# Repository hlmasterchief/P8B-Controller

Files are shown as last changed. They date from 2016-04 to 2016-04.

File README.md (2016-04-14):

# P8B-Controller
Repository for files for an open source gamepad using the Noridc NRF51822 microcontroller.

## Intro
This repository contains all files used to create a BLE gamepad using the Nordic NRF51822 microcontroller. I am using the MDBT40-P module that is approved by Nordic for this project instead of using the NRF51822 directly. 

## File Structure
The schematic and bill of materials can be found at the root layer and Gerber files for the layout can be found in the Gerber directory. The actual project files are found in the Controller directory and the project itself was created with a nightly build of [KiCad](http://kicad-pcb.org/). I used a nightly build because it addresses many issues I was having with the "stable" version of KiCad. For reference I am currently using revision 6687.

## License
This project is released under the Creative Commons Attribution and Share-alike license. The details can be found in LICENSE.txt but in summary, you can use the contents of this project however you want, including commercial use, if you:
1. Release your derivative projects/products with the same license as this one and
2. Attribute me in all derivative works.

###Author Info
[Nate Thompson](mailto:nate@prime8bit.com) <br/>
[http://prime8bit.com](http://prime8bit.com)

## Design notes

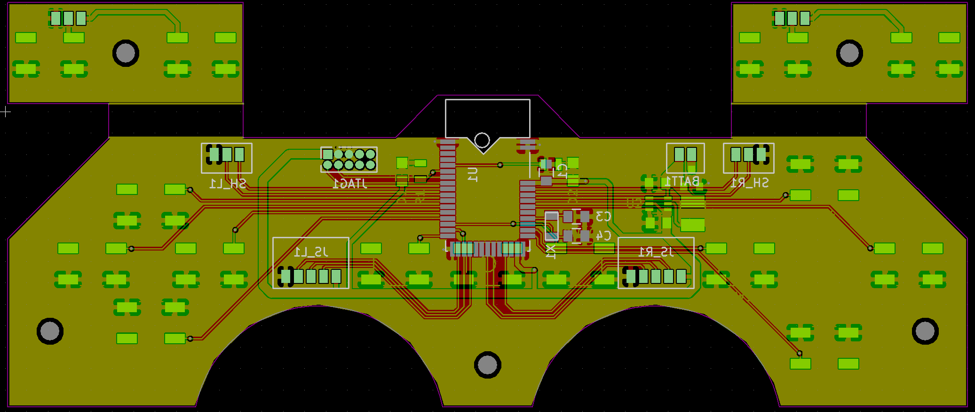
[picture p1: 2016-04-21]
Layout.PNG

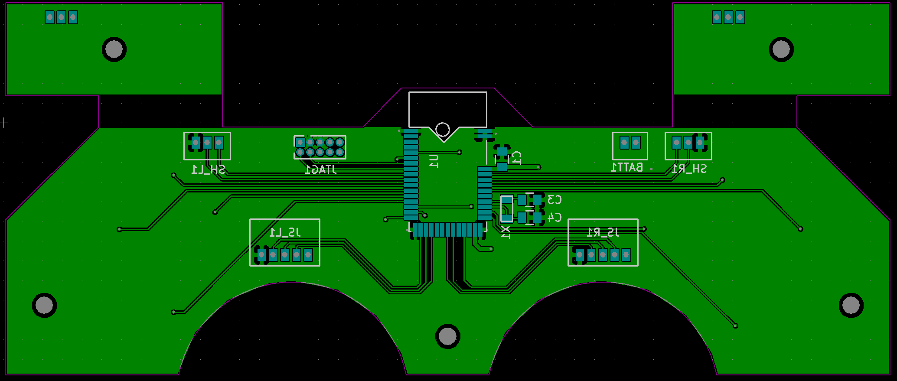
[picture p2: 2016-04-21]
Layout_Back.PNG

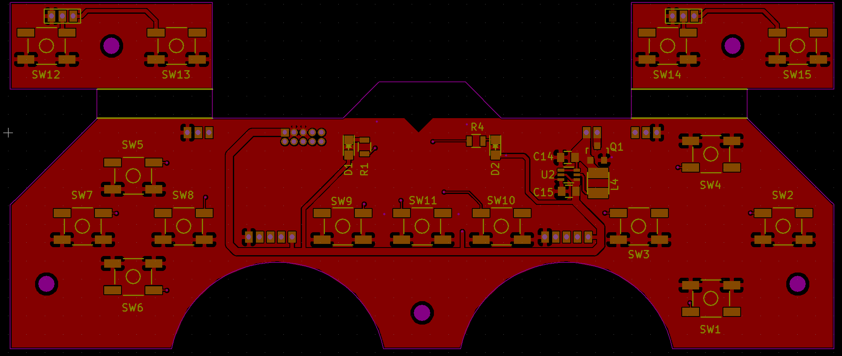
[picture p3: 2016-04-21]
Layout_Front.PNG

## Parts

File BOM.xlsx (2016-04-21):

Reference | Value | Quantity | Price | Price (1500) | Total per board | Total (1500) | Distributor Part Number | Manufacturer Part Number | Misc | Datasheet
R1, R4 | 68 | 2 | 0.1 | 0.00729 | 0.2 | 0.01458 | P68.0CCT-ND | ERJ-6ENF68R0V | RES SMD 68 OHM 1% 1/8W 0805 | http://www.digikey.com/product-detail/en/ERJ-6ENF68R0V/P68.0CCT-ND/1746895
C14, C15 | 10uF | 2 | 0.15 | 0.02888 | 0.3 | 0.05776 | 1276-1122-1-ND | CL21A106KQFNNNE | CAP CER 10UF 6.3V X5R 0805 | http://www.digikey.com/product-detail/en/CL21A106KQFNNNE/1276-1122-1-ND/3889208
C3, C4 | 12pF | 2 | 0.15 | 0.02833 | 0.3 | 0.05666 | 1276-2579-1-ND | CL21C120FBANNNC | Value | http://www.digikey.com/product-detail/en/CL21C120FBANNNC/1276-2579-1-ND/3890665
C1 | 1uF | 1 | 0.1 | 0.01077 | 0.1 | 0.01077 | 1276-1246-1-ND | CL21F105ZOCNNNC | CAP CER 1UF 16V Y5V 0805 | http://www.digikey.com/product-detail/en/CL21F105ZOCNNNC/1276-1246-1-ND/3889332
X1 | 32.768kHz | 1 | 0.76 | 0.4424 | 0.76 | 0.4424 | 1253-1335-1-ND | ST3215SB32768E0HPWBB | Crystal 32.7680kHz 20ppm 9pF 70 kOhm | http://www.digikey.com/product-detail/en/ST3215SB32768E0HPWBB/1253-1335-1-ND/4879221
L4 | 4.7uH | 1 | 0.34 | 0.1564 | 0.34 | 0.1564 | 587-1649-1-ND | NR3015T4R7M | FIXED IND 4.7UH 1.04A 144 MOHM | http://www.digikey.com/product-detail/en/NR3015T4R7M/587-1649-1-ND/1008264
SW1, SW2, SW3, SW4, SW5, SW6, SW7, SW8, SW9, SW10, SW11, SW12, SW13, SW14, SW15 | BUTTON | 15 | 0.65 | 0.3498 | 9.75 | 5.247 | CKN9104CT-ND | PTS525SM15SMTR2 LFS | SWITCH TACTILE SPST-NO 0.02A 15V | http://www.digikey.com/product-detail/en/PTS525SM15SMTR2%20LFS/CKN9104CT-ND/1146923
BATT1 | CONN_BATT | 1 | 0.17 | 0.07237 | 0.17 | 0.07237 | 455-1657-ND | S5B-ZR(LF)(SN) | CONN HEADER ZH TOP 2POS 1.5MM | http://www.digikey.com/product-detail/en/B2B-ZR(LF)(SN)/455-1657-ND/926564
JS_R1, JS_L1 | CONN_JOYSTICK_F | 2 | 0.29 | 0.13075 | 0.58 | 0.2615 | 455-1672-ND | S5B-ZR(LF)(SN) | CONN HEADER ZH SIDE 5POS 1.5MM | http://www.digikey.com/product-detail/en/S5B-ZR(LF)(SN)/455-1672-ND/926579
JTAG1 | CONN_JTAG | 1 | 0.64 | 0.33 | 0.64 | 0.33 | 609-3712-ND | 20021111-00010T4LF | JTAG | http://www.digikey.com/product-detail/en/20021111-00010T4LF/609-3712-ND/2209072
SH_L1, SH_R1 | CONN_SHOULDER | 2 | 0.18 | 0.08051 | 0.36 | 0.16102 | 455-1658-ND | B3B-ZR(LF)(SN) | CONN HEADER ZH TOP 3POS 1.5MM | http://www.digikey.com/product-search/en/connectors-interconnects/rectangular-connectors-headers-male-pins/1442547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
U1 | MDBT40-P | 1 | 7.5 | 5 | 7.5 | 5 | 317030026 | MDBT40P-P256V3 | Price(1500) is a guess | http://www.seeedstudio.com/depot/MDBT40P%C2%A0%C2%A0nRF51822%C2%A0based%C2%A0BLE%C2%A0module-p-2503.html
D1, D2 | ORANGE | 2 | 0.27 | 0.05031 | 0.54 | 0.10062 | 160-1413-1-ND | LTST-C170KFKT | LED ORANGE CLEAR 0805 SMD | http://www.digikey.com/product-detail/en/LTST-C170KFKT/160-1413-1-ND/386774
U2 | TPS61221 | 1 | 1.52 | 0.5575 | 1.52 | 0.5575 | 296-24171-2-ND | TPS61221DCKT | http://www.digikey.com/product-detail/en/TPS61221DCKT/296-24171-2-ND/2003233 | http://www.digikey.com/product-detail/en/TPS61221DCKT/296-24171-1-ND/2003239
Q1 | DMN2050L | 1 | 0.41 | 0.1575 | 0.41 | 0.1575 | DMN2050LDICT-ND | DMN2050L-7 | Alternate - SI2312 | http://www.digikey.com/product-detail/en/diodes-incorporated/DMN2050L-7/DMN2050LDICT-ND/1964751
Case | Case | 1 | 5 | 5 | 5 | 5
 |  |  |  | Total | 28.47 | 17.62608

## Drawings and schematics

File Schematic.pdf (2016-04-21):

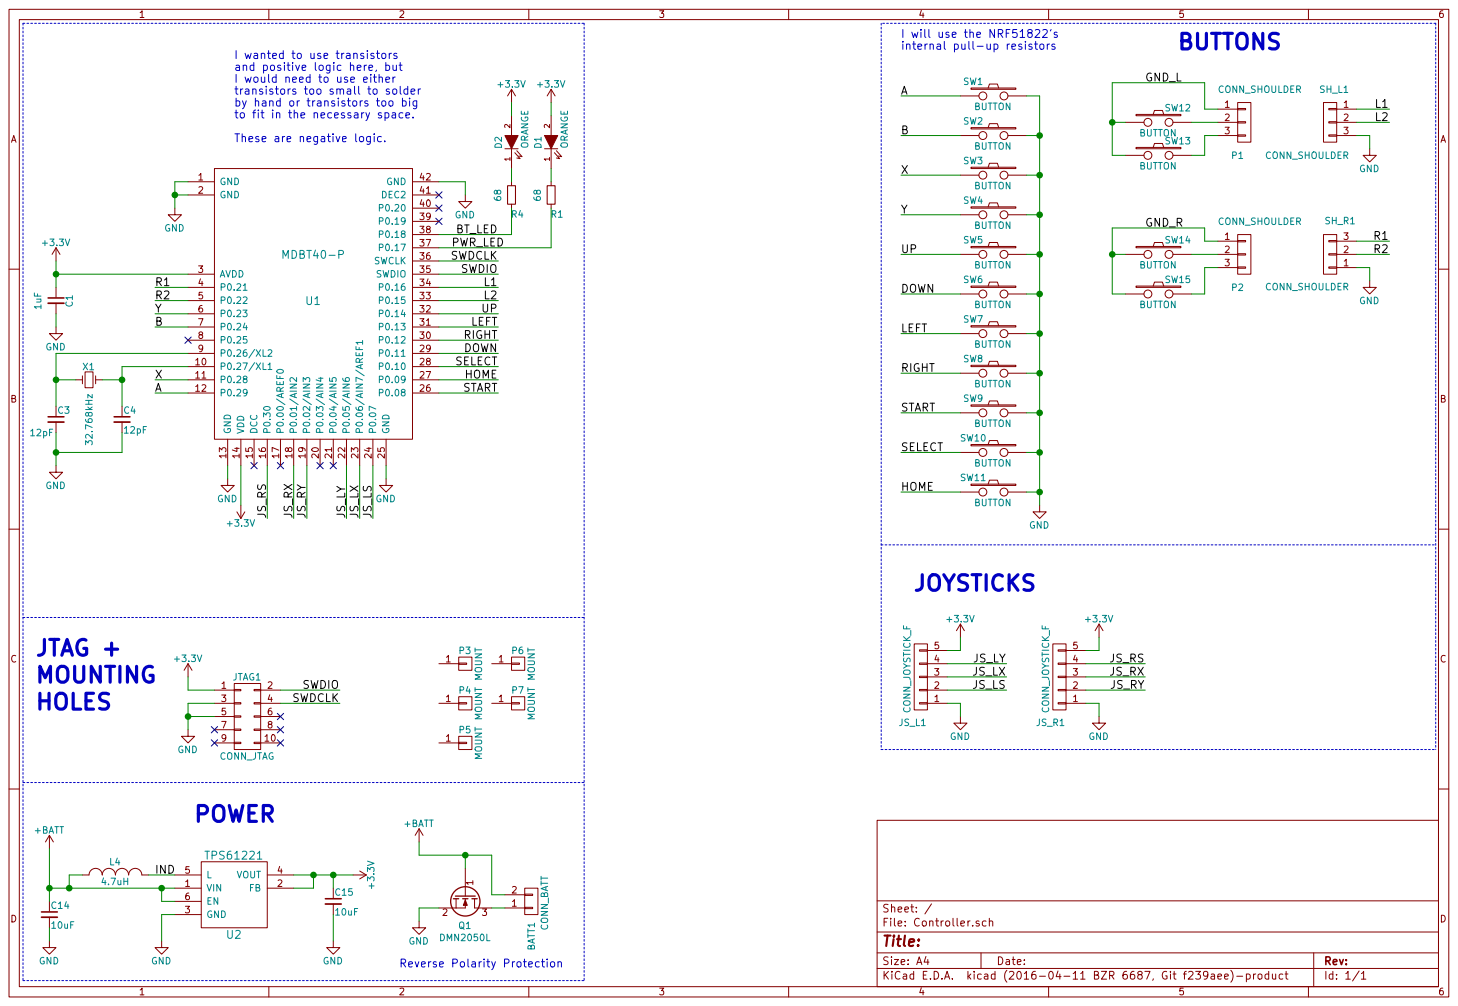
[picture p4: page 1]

I wanted to use transistors and positive logic here, but
I would need to use either
transistors too small to solder by hand or transistors too big
to fit in the necessary space.

Id: 1/1 Title: File: Controller.sch Sheet: /

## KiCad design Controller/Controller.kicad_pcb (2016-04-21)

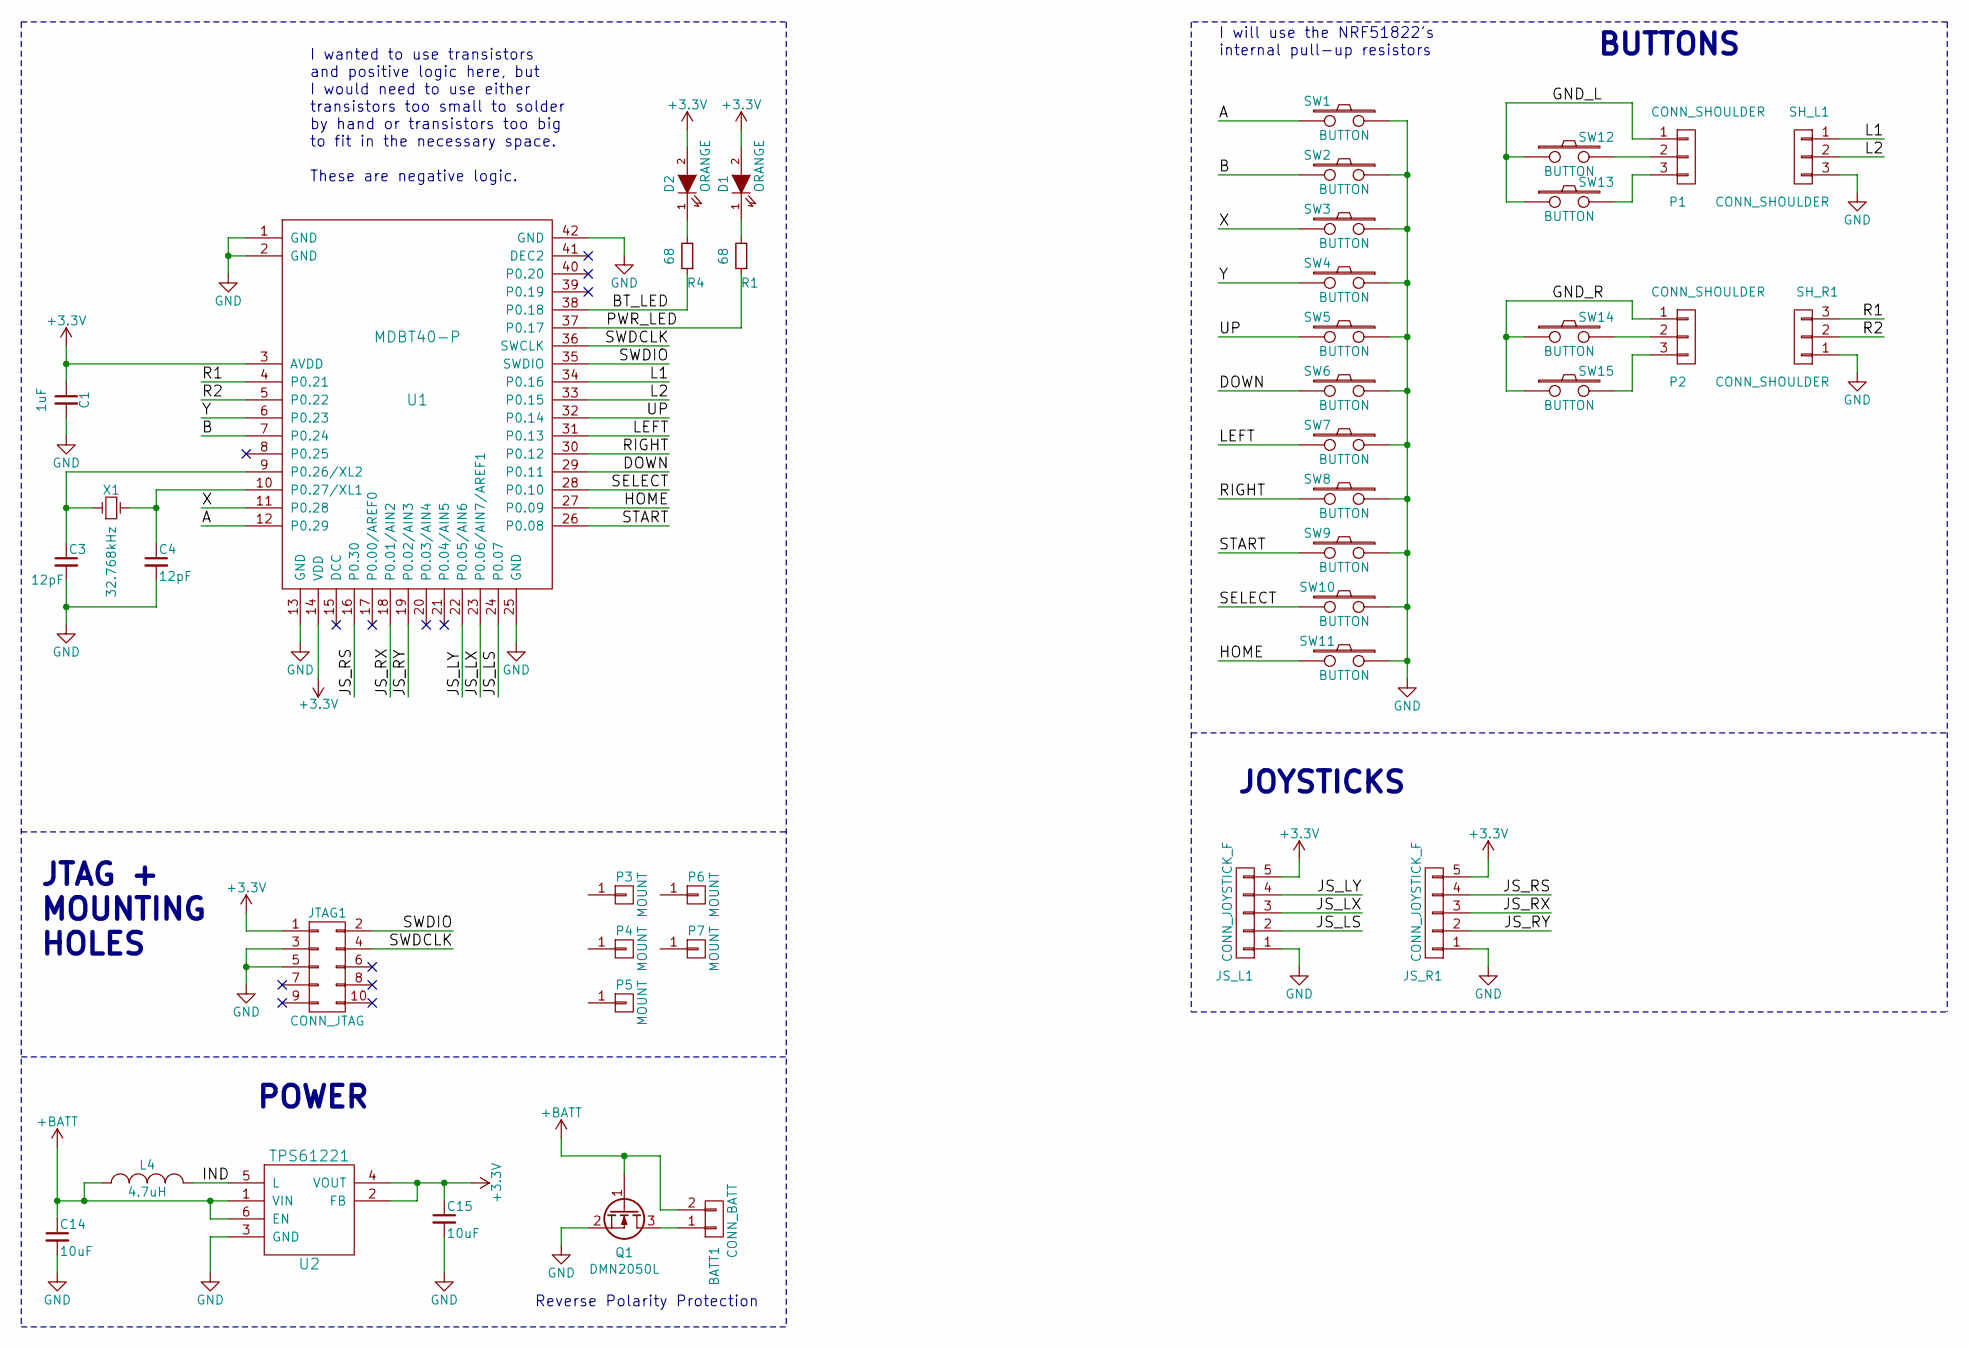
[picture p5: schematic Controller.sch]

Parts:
BATT1: CONN_BATT; Manufacturer Part Number S5B-ZR(LF)(SN)
C1: 1uF; C_0805; Manufacturer Part Number CL21F105ZOCNNNC
C3, C4: 12pF; C_0805; Manufacturer Part Number CL21C120FBANNNC
C14, C15: 10uF; C_0805; Manufacturer Part Number CL21A106KQFNNNE
D1, D2: ORANGE; LED_0805; Manufacturer Part Number LTST-C170KFKT
JS_L1: CONN_JOYSTICK_F; CONN_JOYSTICK; Manufacturer Part Number S5B-ZR(LF)(SN)
JS_R1: CONN_JOYSTICK_F; CONN_JOYSTICK; Manufacturer Part Number S5B-ZR(LF)(SN)
JTAG1: CONN_JTAG; Pin_Header_Straight_2x05_Pitch1.27mm; Manufacturer Part Number 20021111-00010T4LF
L4: 4.7uH; NR3015T4R7M; Manufacturer Part Number NR3015T4R7M
P1, P2: CONN_SHOULDER; CONN_SHOULDER_M; Manufacturer Part Number B3B-ZR(LF)(SN)
P3, P4, P5, P6, P7: MOUNT; Mounting_#2
Q1: DMN2050L; SOT-23-3; Manufacturer Part Number DMN2050L-7
R1, R4: 68; R_0805; Manufacturer Part Number ERJ-6ENF68R0V
SH_L1: CONN_SHOULDER; CONN_SHOULDER_F; Manufacturer Part Number B3B-ZR(LF)(SN)
SH_R1: CONN_SHOULDER; CONN_SHOULDER_F; Manufacturer Part Number B3B-ZR(LF)(SN)
SW1, SW2, SW3, SW4, SW5, SW6, SW7, SW8, SW9, SW10, SW11, SW12, SW13, SW14, SW15: BUTTON; SW_BUTTON; Manufacturer Part Number PTS525SM15SMTR2 LFS
U1: MDBT40-P; Manufacturer Part Number MDBT40P-P256V3
U2: TPS61221; Manufacturer Part Number TPS61221DCKT
X1: 32.768kHz; Manufacturer Part Number ST3215SB32768E0HPWBB

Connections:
+3V3: C1.1, C15.1, D1.2 (A), D2.2 (A), JS_L1.5, JS_R1.5, JTAG1.1, U1.3 (AVDD), U1.14 (VDD), U2.2 (FB), U2.4 (VOUT)
+BATT: BATT1.2, C14.1, L4.1, Q1.1 (G), U2.1 (VIN), U2.6 (EN)
/A: SW1.2, U1.12 (P0.29)
/B: SW2.2, U1.7 (P0.24)
/BT_LED: R4.1, U1.38 (P0.18)
/DOWN: SW6.2, U1.29 (P0.11)
/GND_L: P1.1, SW12.1, SW13.1
/GND_R: P2.1, SW14.1, SW15.1
/HOME: SW11.2, U1.27 (P0.09)
/IND: L4.2, U2.5 (L)
/JS_LS: JS_L1.2, U1.24 (P0.07)
/JS_LX: JS_L1.3, U1.23 (P0.06/AIN7/AREF1)
/JS_LY: JS_L1.4, U1.22 (P0.05/AIN6)
/JS_RS: JS_R1.4, U1.16 (P0.30)
/JS_RX: JS_R1.3, U1.18 (P0.01/AIN2)
/JS_RY: JS_R1.2, U1.19 (P0.02/AIN3)
/L1: SH_L1.1, U1.34 (P0.16)
/L2: SH_L1.2, U1.33 (P0.15)
/LEFT: SW7.2, U1.31 (P0.13)
/PWR_LED: R1.1, U1.37 (P0.17)
/R1: SH_R1.3, U1.4 (P0.21)
/R2: SH_R1.2, U1.5 (P0.22)
/RIGHT: SW8.2, U1.30 (P0.12)
/SELECT: SW10.2, U1.28 (P0.10)
/START: SW9.2, U1.26 (P0.08)
/SWDCLK: JTAG1.4, U1.36 (SWCLK)
/SWDIO: JTAG1.2, U1.35 (SWDIO)
/UP: SW5.2, U1.32 (P0.14)
/X: SW3.2, U1.11 (P0.28)
/Y: SW4.2, U1.6 (P0.23)
GND: C1.2, C3.2, C4.2, C14.2, C15.2, JS_L1.1, JS_R1.1, JTAG1.3, JTAG1.5, Q1.2 (S), SH_L1.3, SH_R1.1, SW1.1, SW2.1, SW3.1, SW4.1, SW5.1, SW6.1, SW7.1, SW8.1, SW9.1, SW10.1, SW11.1, U1.1 (GND), U1.2 (GND), U1.13 (GND), U1.25 (GND), U1.42 (GND), U2.3 (GND)
unnamed: BATT1.1, Q1.3 (D)
unnamed: C3.1, U1.9 (P0.26/XL2), X1.1
unnamed: C4.1, U1.10 (P0.27/XL1), X1.2
unnamed: D1.1 (K), R1.2
unnamed: D2.1 (K), R4.2
unnamed: P1.2, SW12.2
unnamed: P1.3, SW13.2
unnamed: P2.2, SW14.2
unnamed: P2.3, SW15.2

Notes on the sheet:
POWER
JTAG + MOUNTING HOLES
I wanted to use transistors and positive logic here, but I would need to use either transistors too small to solder by hand or transistors too big to fit in the necessary space. These are negative logic.
Reverse Polarity Protection
I will use the NRF51822's internal pull-up resistors
BUTTONS
JOYSTICKS

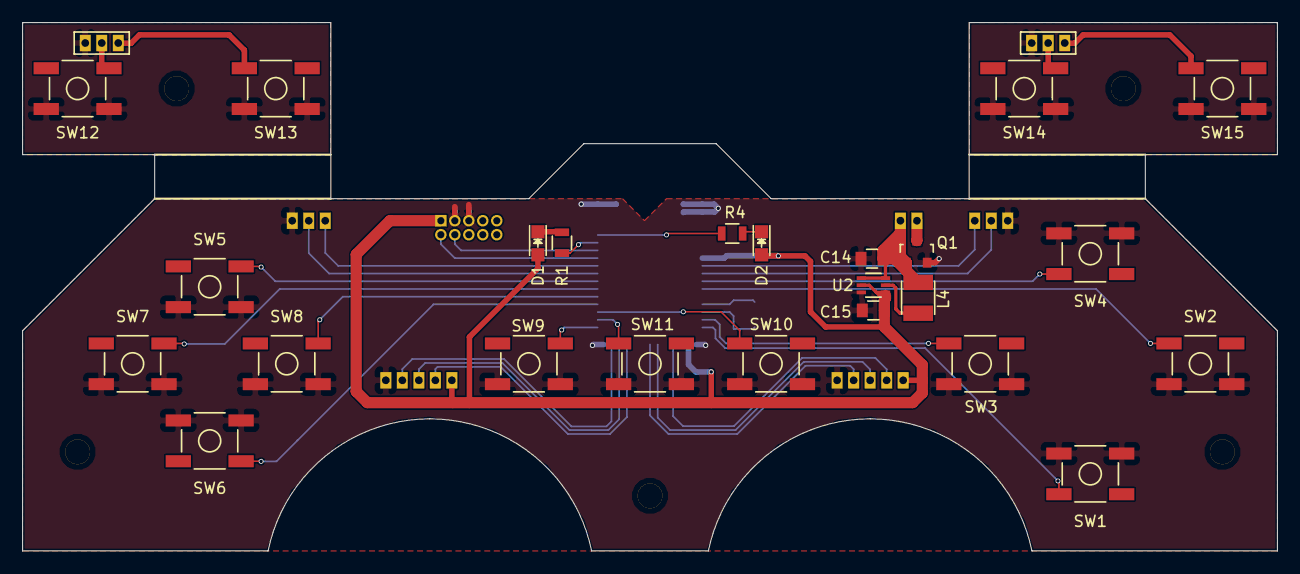
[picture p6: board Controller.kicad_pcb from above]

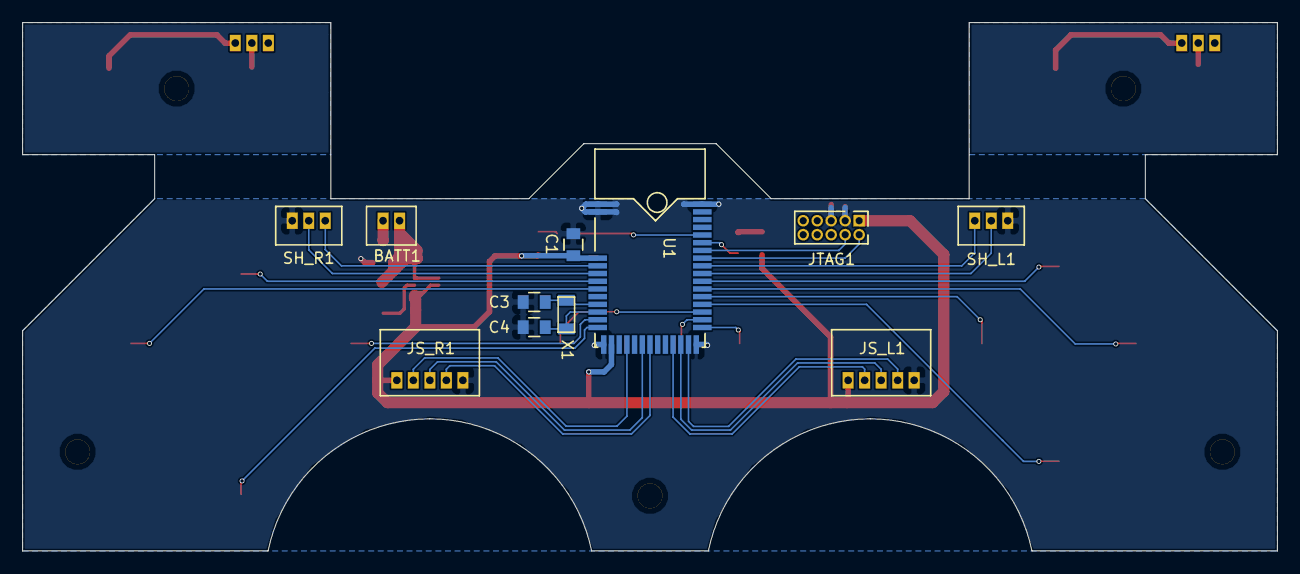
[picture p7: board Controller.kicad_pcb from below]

Board: 2 copper layers, 114.0 x 48.0 mm, 42 parts (11 on the bottom side), 40 nets.

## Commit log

2016-04-14 Initial Commit.
    [BOM.xlsx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]
2016-04-14 Renamed Schematic for clarity.
2016-04-21 Improved traces in power supply circuit. Added clearance on inside of drill holes. Removed sharp inside corners and replaced with cirular cutouts. Removed removed pull-down resistors because I am usi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
    [Controller.kicad_pcb, Controller.sch, Input.sch]
2016-04-21 Improved routing for power supply circuit. Added clearance to inside of screw holes. Replaced sharp inner corners on bottom of the board with round holes. Removed pull-down resistors and opted for ne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
    [Controller-B.Cu.gbr, Controller-B.Mask.gbr, Controller-B.SilkS.gbr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]
2016-04-21 Updated BOM.xlsx
    [BOM.xlsx]
